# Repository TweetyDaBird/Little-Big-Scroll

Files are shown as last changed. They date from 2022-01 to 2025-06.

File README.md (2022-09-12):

# Little Big Scroll

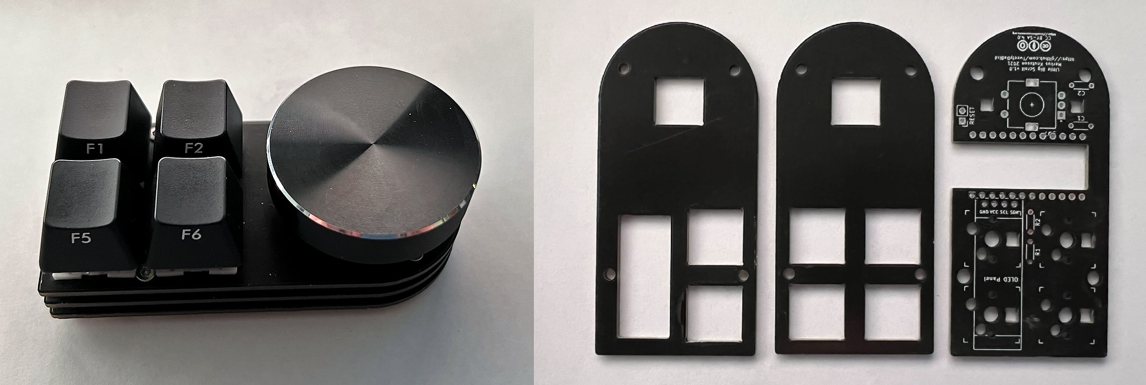
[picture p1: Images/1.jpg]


## A family of low-cost and easy to build macro pads. 
Usable for Media control, macro buttons, or just about anything else you can imagine and code in QMK.

### The 'family' includes:
- **Little Big Scroll 6** - 6 Cherry MX compatible buttons, one Ø40 mm encoder wheel with button. (Prototype being tested)
- **Little Big Scroll 4** - 2 or 4 Cherry MX compatible buttons, one Ø40 mm encoder wheel with button, optional 128x32px OLED. (Complete and available for sale/manufacturing)
- **Little Big Scroll** - A single Ø40 mm encoder wheel with button. (Design completed, pending prototype)

### Common specifications
- Use a Promicro or equivalent controller
- Programmable with QMK and VIAL
- Cherry MX style keyswitches
- Kaihl hot swap sockets
- Clickable Rotary encoder with up to 40mm wheel
- Designed with a complete sandwich case for an easy build (If purchased, comes as a complete kit)
- Optional Per Key RGB / Encoder Underglow
- (LBS 4) Optional 0.91" 128x32 OLED screen

## Buildguide

### Step-by-step
- Solder hotswap sockets in markings
- Solder capacitors C1, C2 in markings
- **LSB 4 only** - If you are mounting the OLED, solder Resistors R1, R2 & OLED Screen in place
- Solder Encoder
- Solder controller, face up, flush with underside of PCB (*)
- Assemble plate/spacers around the PCB (**)
- Insert switches/caps (remember to support the sockets!) and add encoder wheel
- Program
- Enjoy!

(*) The controller can be socketed, but that adds height, and you need longer spacers than the ones included if purchasing a kit.

(**) For LSB 4, the unused plate forms the bottom, unless a solid backplate is added as an optional extra. Breakaway tabs need to be removed and filed before use.

## Buy a kit!
I sell complete kits, making it easy to build your keyboard, and it also supports prototypes for new wacky ones. 



## Discord for build help and discussions!

<a href="https://discord.gg/G6QzcJQUnm">Discuss on Discord</a>

## License

[][cc-by-sa] - This work is licensed under a
[Creative Commons Attribution-ShareAlike 4.0 International License][cc-by-sa].

[cc-by-sa]: http://creativecommons.org/licenses/by-sa/4.0/
[cc-by-sa-shield]: https://img.shields.io/badge/License-CC%20BY--SA%204.0-lightgrey.svg

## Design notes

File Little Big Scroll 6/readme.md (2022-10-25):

# Little Big Scroll 6



A low-cost and easy to build macro pad intended for amongst other things media controls. 

- Uses a Promicro/Elite C or equivalent controller
- Programmable with QMK and VIAL
- Cherry MX style keyswitches
- Kaihl hot swap sockets
- Clickable Rotary encoder with up to 40mm wheel
- Optional Per Key RGB
- Designed with a complete sandwich case for an easy build

## BOM
| Name of part | Qty. | Remarks | Aliexpress |
| --- | ---- | --- | --- |
| PCB | 1 | 1,6 mm thick | X |
| Front Plate  | 1 |1,6 mm thick| X |
| Rear Plate | 1 | 1,6 mm thick| X |
| Kailh hotswap socket | 6 | | [link](https://www.aliexpress.com/item/-/4001051840976.html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) |
| Capacitors 100 nF | 2 | Needed for Rotary Encoder. | [link](https://www.aliexpress.com/item/-/32971478818.html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) |
| M2 * 7/8 mm standoff | 4 | Round, max 3.7 mm in diameter | [link](https://www.aliexpress.com/item/-/32863484622.html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) |
| M2 * 4 mm screw | 8 | 4-8 mm length fits, low profile hex head recommended | [link](https://www.aliexpress.com/item/-/32966917947.html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) |
| Silicon pads | 4 |  | [link](https://www.aliexpress.com/item/-/32912066603.html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) |
| Pro Micro | 1 | Can be built with various ProMicro clones as well as Elite C | [link](https://www.aliexpress.com/item/-/32849563958.html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) |
| Rotary Encoder | 1 || [link](https://www.aliexpress.com/item/10000056483250.html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,searchweb201602_,searchweb201603_) |
| Rotary Encoder Knob | 1 | Clearance for max 40 mm diameter, pick halfshaft or spline according to encoder choice.  | [link](https://www.aliexpress.com/item/10000056483250.html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,searchweb201602_,searchweb201603_) |
| RGB LED's | 8 | **- Optional -** SK6812 mini-E | [link](https://www.aliexpress.com/item/4000475685852.html) |

## Buildguide

### Step-by-step
- Solder hotswap sockets in markings
- Solder capacitors C1, C2 in markings
- Solder Encoder
- Solder controller, face up, flush with underside of PCB
- Assemble plate/spacers
- Insert switches and add encoder wheel
- Program
- Enjoy!

## License
[][cc-by-sa]  -  This work is licensed under a
[Creative Commons Attribution-ShareAlike 4.0 International License][cc-by-sa].

[cc-by-sa]: http://creativecommons.org/licenses/by-sa/4.0/
[cc-by-sa-image]: https://licensebuttons.net/l/by-sa/4.0/88x31.png
[cc-by-sa-shield]: https://img.shields.io/badge/License-CC%20BY--SA%204.0-lightgrey.svg

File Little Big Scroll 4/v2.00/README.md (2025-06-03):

# Little Big Scroll 4 v2



A low-cost and easy to build macro pad intended for among other things media controls. 

- Uses an RP2040 Zero or equivalent controller
- Programmable with QMK and VIAL
- Cherry MX style keyswitches
- Kaihl hot swap sockets
- Clickable Rotary encoder with up to 40mm wheel
- Optional Per Key RGB
- Designed with a complete sandwich case for an easy build

## BOM
| Name of part | Qty. | Remarks | Aliexpress |
| --- | ---- | --- | --- |
| PCB | 1 | 1,6 mm thick | X |
| Plate Front  | 1 |1,6 mm thick| X |
| Plate Rear | 1 | 1,6 mm thick| X |
| Kailh hotswap socket | 4 | Qty. depends on layout. | [link](https://www.aliexpress.com/item/-/4001051840976.html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) |
| Capacitors 100 nF | 2 | Needed for Rotary Encoder. | [link](https://www.aliexpress.com/item/-/32971478818.html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) |
| M2 * 7/8 mm standoff | 4 | Round, max 3.7 mm in diameter | [link](https://www.aliexpress.com/item/-/32863484622.html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) |
| M2 * 4 mm screw | 8 | 4-8 mm length fits, low profile hex head recommended | [link](https://www.aliexpress.com/item/-/32966917947.html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) |
| Silicon pads | 4 |  | [link](https://www.aliexpress.com/item/-/32912066603.html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) |
| RP2040 Zero | 1 | | [link](https://www.aliexpress.com/item/1005003504006451.html) |
| Rotary Encoder | 1 || [link](https://www.aliexpress.com/item/10000056483250.html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,searchweb201602_,searchweb201603_) |
| Rotary Encoder Knob | 1 | Clearance for max 40 mm diameter, pick halfshaft or spline according to encoder choice.  | [link](https://www.aliexpress.com/item/10000056483250.html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,searchweb201602_,searchweb201603_) |
| RGB LED's | 6 | **- Optional -** SK6812 mini-E | [link](https://www.aliexpress.com/item/4000475685852.html) |

## Buildguide

### Step-by-step
- Solder hotswap sockets in markings on rear of PCB
- Solder capacitors C1, C2 in markings on rear of PCB
- Solder Encoder (Place from front, solder on the back)
- Solder controller (**Place behind the PCB**, buttons facing up).
- Assemble plate & spacers.
- Insert switches and add encoder wheel
- Program
- Enjoy!

## License
[][cc-by-sa]  -  This work is licensed under a
[Creative Commons Attribution-ShareAlike 4.0 International License][cc-by-sa].

[cc-by-sa]: http://creativecommons.org/licenses/by-sa/4.0/
[cc-by-sa-image]: https://licensebuttons.net/l/by-sa/4.0/88x31.png
[cc-by-sa-shield]: https://img.shields.io/badge/License-CC%20BY--SA%204.0-lightgrey.svg

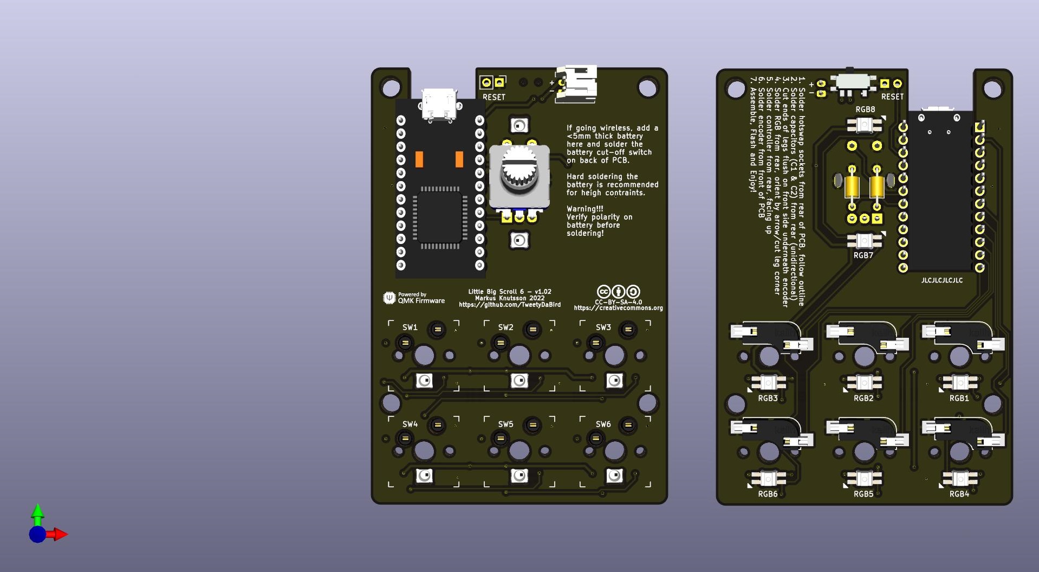
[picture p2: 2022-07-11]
Images/Ny mapp/Little Big Scroll 6 front.jpg

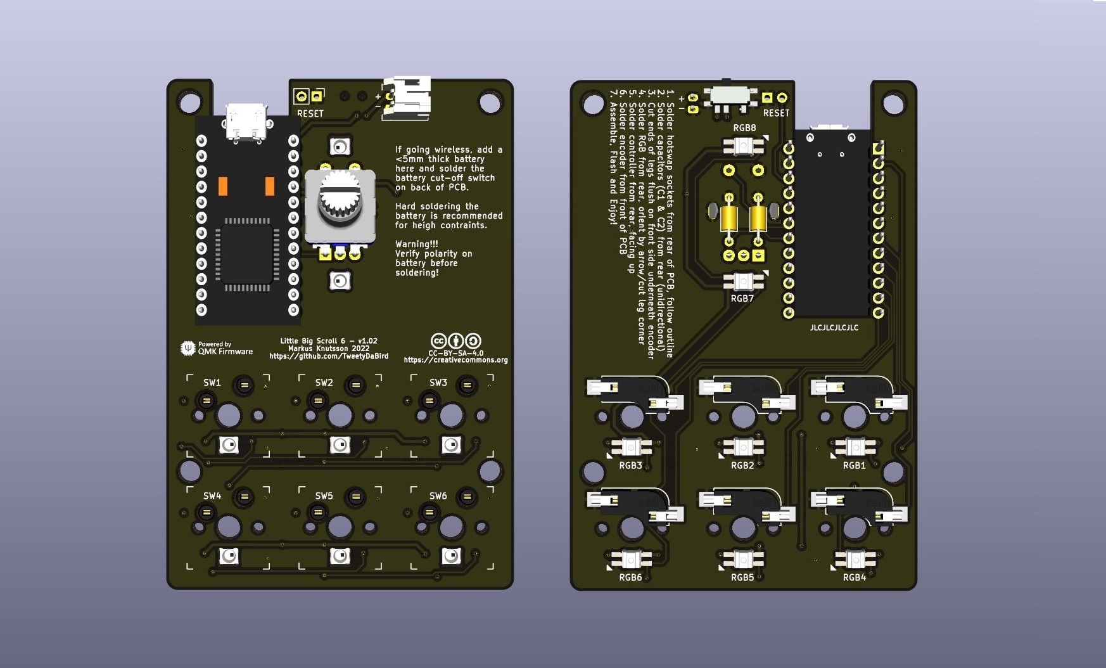
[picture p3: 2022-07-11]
Images/Ny mapp/Little Big Scroll 6 composite.jpg

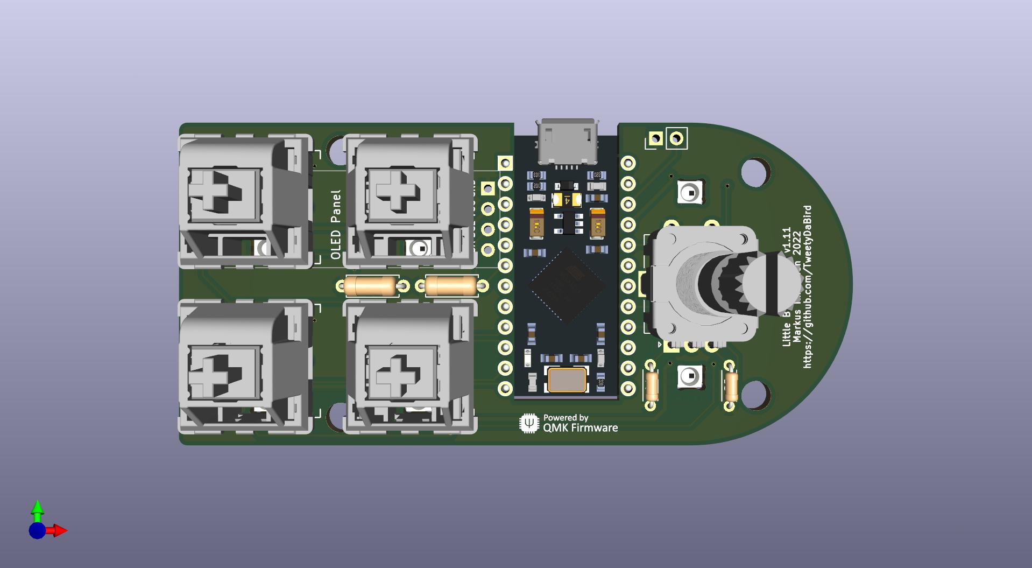
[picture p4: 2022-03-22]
Images/Little_Big_Scroll_4_front.jpg

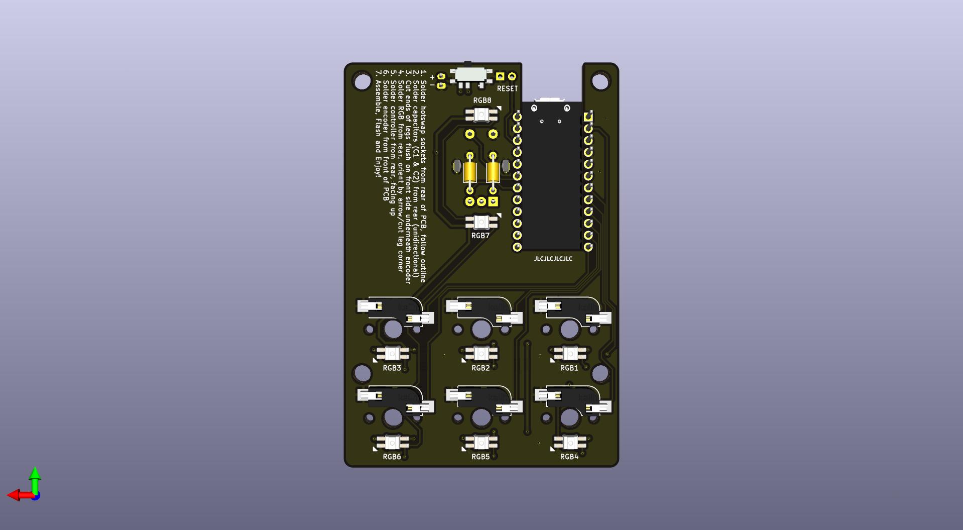
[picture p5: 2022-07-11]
Images/Ny mapp/Little Big Scroll 6 rear.jpg

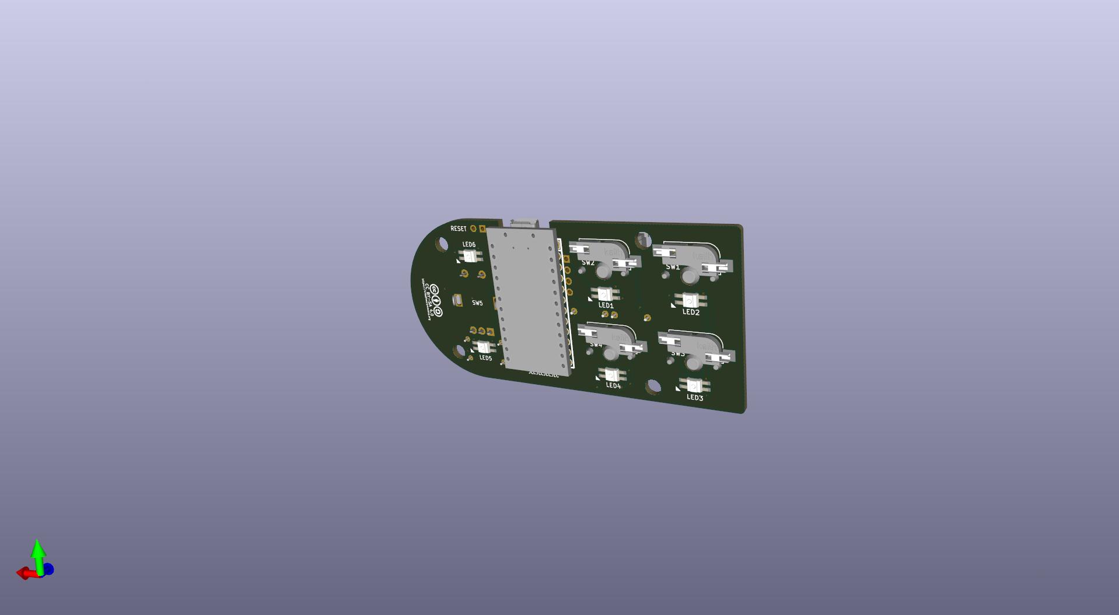
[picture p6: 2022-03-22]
Images/Little_Big_Scroll_4_back.jpg

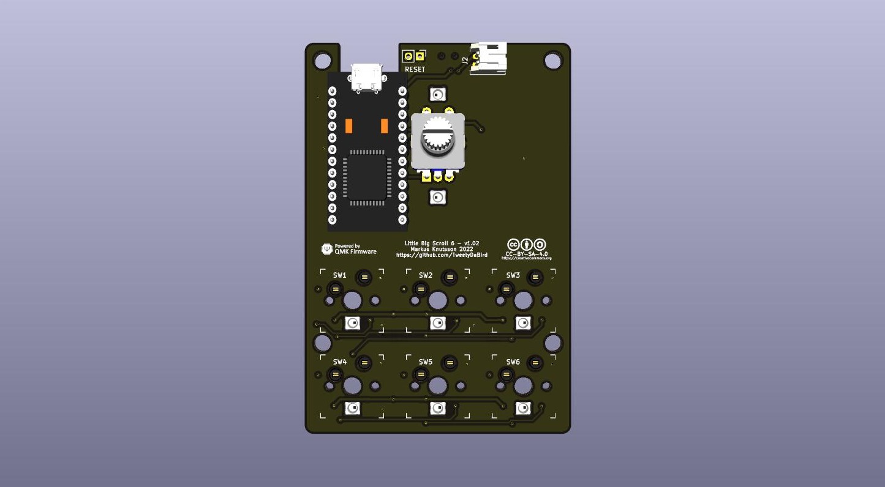
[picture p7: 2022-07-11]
Images/Little Big Scroll 6 2.jpg

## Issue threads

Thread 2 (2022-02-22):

Vial-QMK Firmware source code

kroegerama, 2022-02-22:
This is an interesting project, but where can I find the source code of your hex file?

I can't find the Little-Big-Scroll in [`vial-qmk`](https://github.com/vial-kb/vial-qmk/tree/vial/keyboards/) or in your fork of [`qmk-firmware`](https://github.com/TweetyDaBird/qmk_firmware/tree/tweetydabird/keyboards).

TweetyDaBird, 2022-02-22:
That’s because I’m lazy and haven’t finished tweaking them yet. I got distracted playing with the prototype for the LittleBigScroll 6 instead. I’ll get around to finish them in a couple of days probably.

kroegerama, 2022-02-22:
Oh, I can totally relate to that 😄  Thanks for letting me know!

TweetyDaBird, 2022-03-22:
Well, life keeps interfering unfortunately. I will get to to it I promise.

Side note, what kind of troubleshooting is it you need the firmware for? All the info you would ever need is in the pdf file with the schematic.

lesshonor, 2022-04-27:
Late, but the disconnect ended up being that the seller of the PCBs used the v1.1 release to get the files made, and that has _wildly_ different pin definitions from "v1.11".
(Would you consider calling this "rev 2" so that distinction is clearer? These are breaking changes. https://semver.org/)

TweetyDaBird, 2022-04-27:
Well, considering nothing reached beyond pre-releases before v1.11 I think it should be fine as is, although I can understand the confusion.

Brittle73, 2022-06-15:
> That’s because I’m lazy and haven’t finished tweaking them yet. I got distracted playing with the prototype for the LittleBigScroll 6 instead. I’ll get around to finish them in a couple of days probably.

Do you have an update?

TweetyDaBird, 2022-10-01:
LSB 4 & LSB 6 is now in main QMK repo, so should be less confusing.

* Note that using QMK online Configurator still isn't a great idea, since the main feature, ie the encoder won't work in that case.

VIAL firmware is available in my fork, but remains WIP for now.

TweetyDaBird, 2022-10-25:
VIAL is merged into main Git, source code is available, and pre configured .HEX files are available in this Git

Closed 2022-10-25.

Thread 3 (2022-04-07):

QMK keyboard firmware

kilokeith, 2022-04-07:
Hi, I've putting together a Little Big Scroll 4, but I'm stuck at the programming step. What keyboard should I tell QMK that I'm flashing?
I do se the .hex file in this project, and I can flash that... but then what? Where should I start with putting together a layout?

Thanks! This is a nice project.

TweetyDaBird, 2022-04-08:
Thanks for the praise, but unfortunately you will get a slightly testy reply back, as this is a clear issue of not reading, not the instructions being unclear in any way. I will however update them to be overly obvious from now on, as this seems to be a common issue.

Why do people insist on trying to 'tell QMK what keyboard they are flashing'? The label on that drop box clearly states "Keyboard from qmk.fm" meaning it will download the firmware for the keyboard you select from that database. And obviously if the keyboard is not in that database, you cannot download it from there.

The dropdown has nothing to do with what keyboard you are flashing, but with what file you want to download. If you were in fact using QMK and building your own layout as you allude to, selecting a firmware from here would flash the default firmware with the default layout as downloaded, not your own layout.

The supplied .HEX file is for VIAL-QMK. Download the software [here](https://get.vial.today) and then you have all the options to dynamically assign keys, just like VIA does, only open source. The firmware supports RGB as backlight, not a matrix, since 2*3 is a bit limiting anyways.

If you very much prefer to use QMK without VIAL, you will either have to build the firmware on your own from the files supplied in the QMK git under my username, or wait until its in the QMK main git.

Brittle73, 2022-06-15:
Seconding this...

Got ghosted by you on Tindie after weeks of discussion over this. Let's not be "testy" with people who are nicely and justifiably requesting support on an open source platform like OP here. Their request was overwhelmingly positive and reasonable. QMK _is_ open source and the provided firmware for VIAL does not perform all of the functionality advertised with the product. They just asked for assistance with the product you sold them.

TweetyDaBird, 2022-06-15:
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

Sorry you feel that way. I have been working on the firmware the last week or so every free night, and it should be ready to be published in a nights work or two, giving you all a base to work from.

The 'ghosting' is probably more part of me leaving tindie altogether since they refuse to do anything to support EU tax rules, or any form of shipping calculations, meaning I was making losses on all shipping. Right now the shop there is sort of deactivated and about to time out.

TweetyDaBird, 2022-10-01:
LSB 4 & LSB 6 is now in main QMK repo, so should be less confusing.

* Note that using QMK Configurator still isn't a great idea, since the main feature, ie the encoder won't work in that case.

Closed 2022-10-01.

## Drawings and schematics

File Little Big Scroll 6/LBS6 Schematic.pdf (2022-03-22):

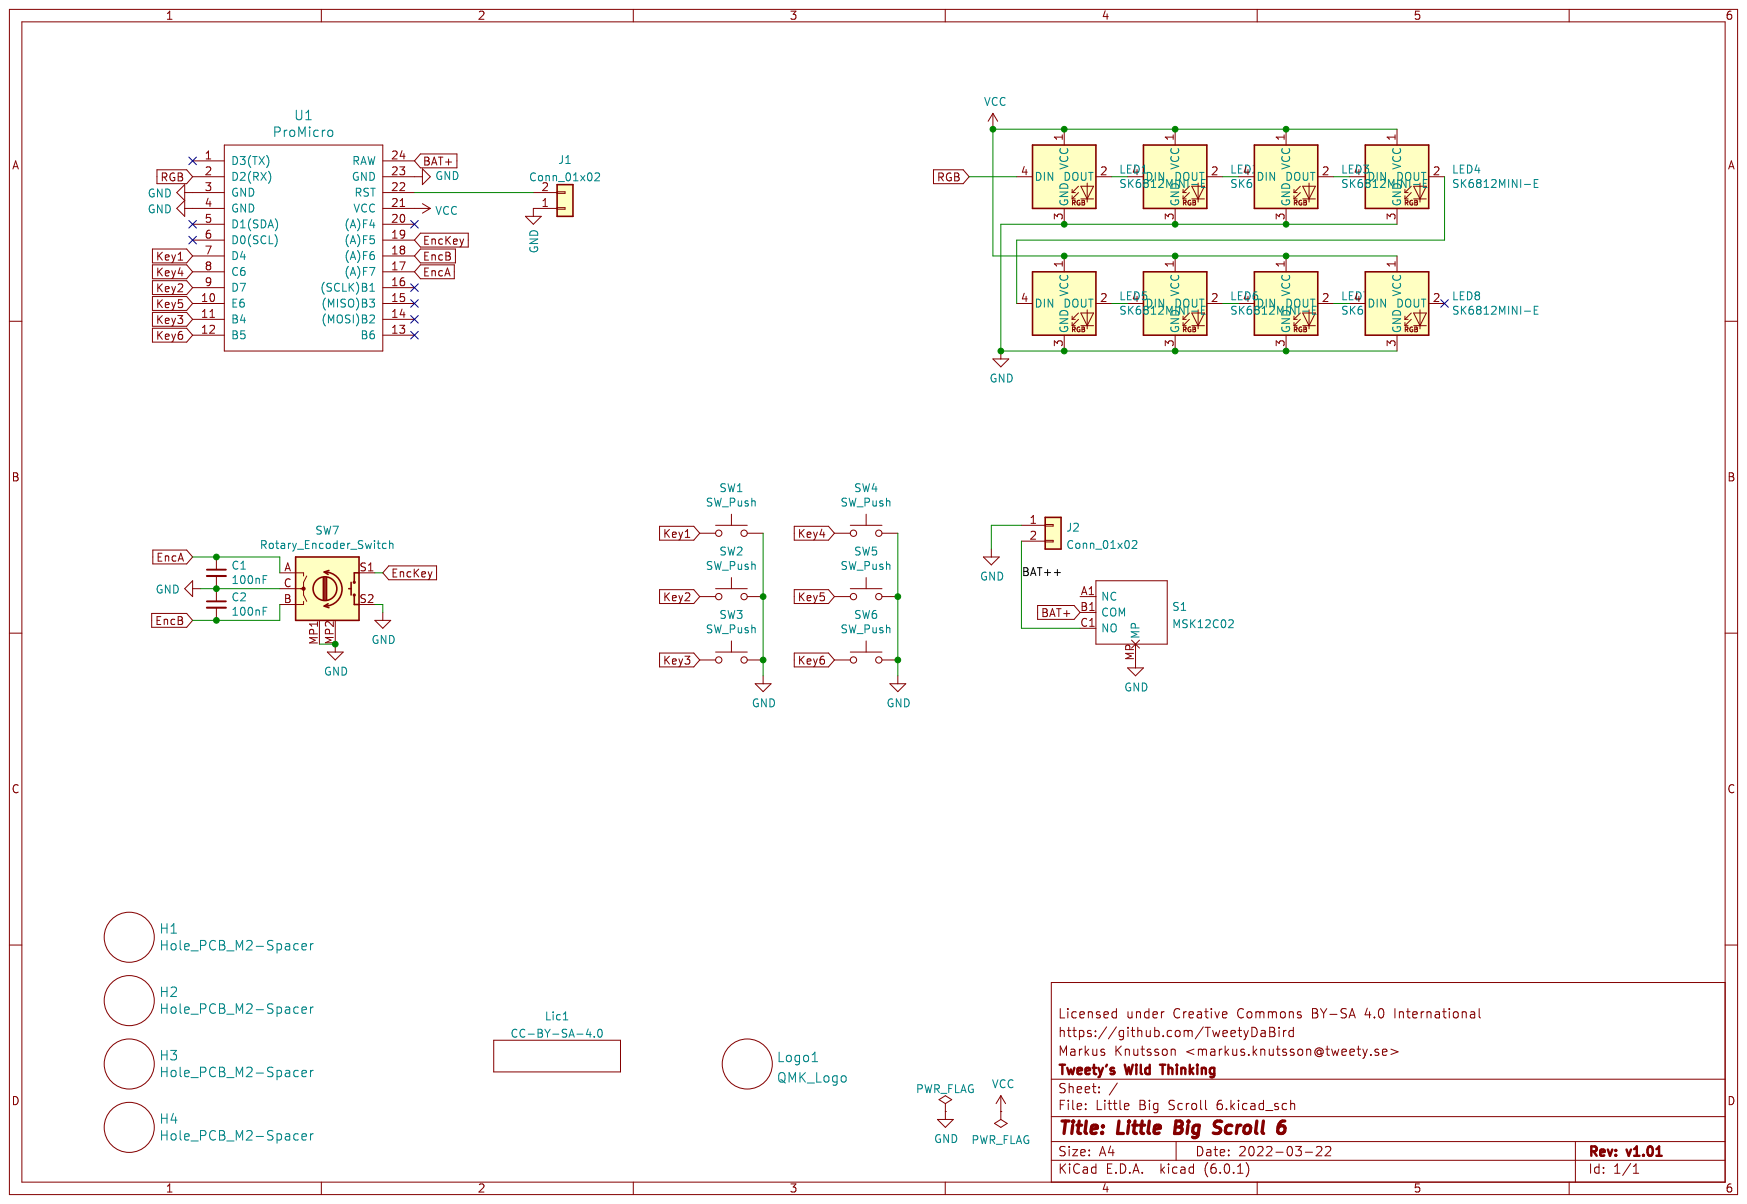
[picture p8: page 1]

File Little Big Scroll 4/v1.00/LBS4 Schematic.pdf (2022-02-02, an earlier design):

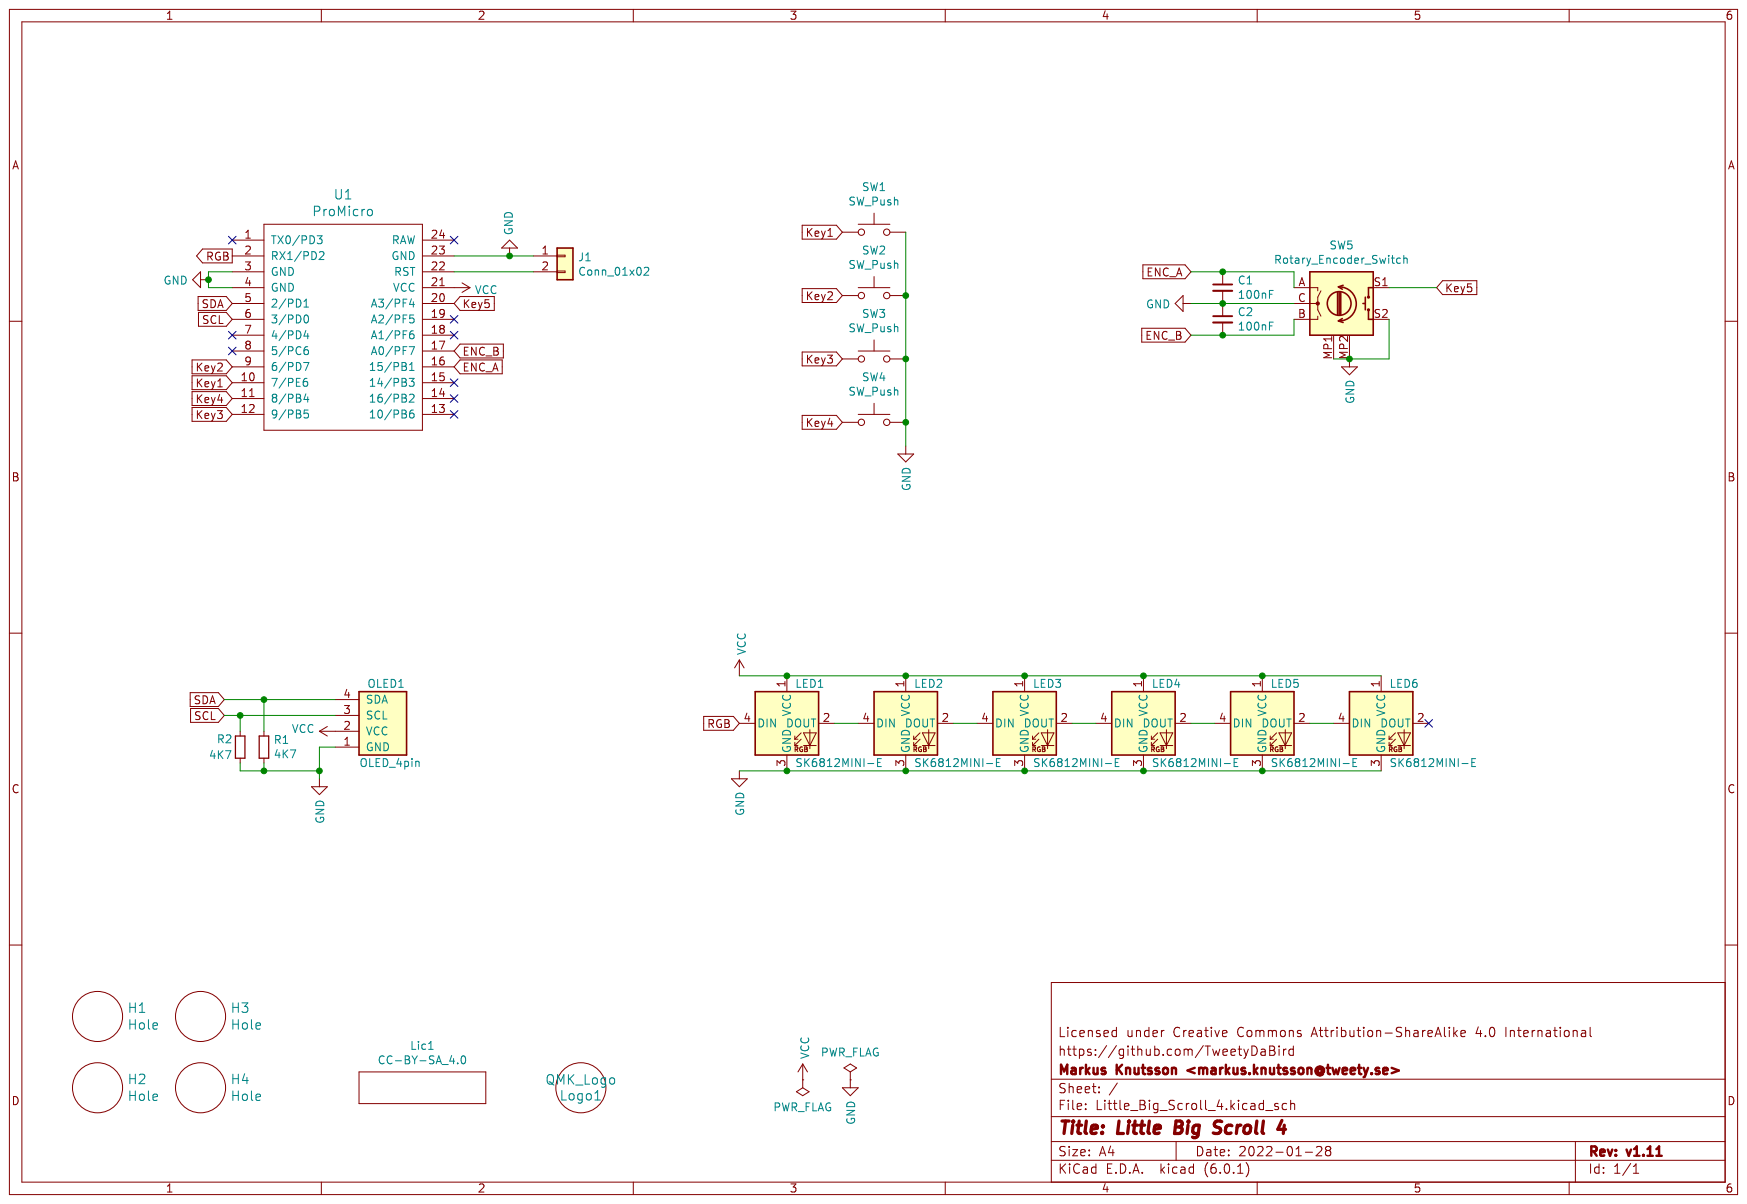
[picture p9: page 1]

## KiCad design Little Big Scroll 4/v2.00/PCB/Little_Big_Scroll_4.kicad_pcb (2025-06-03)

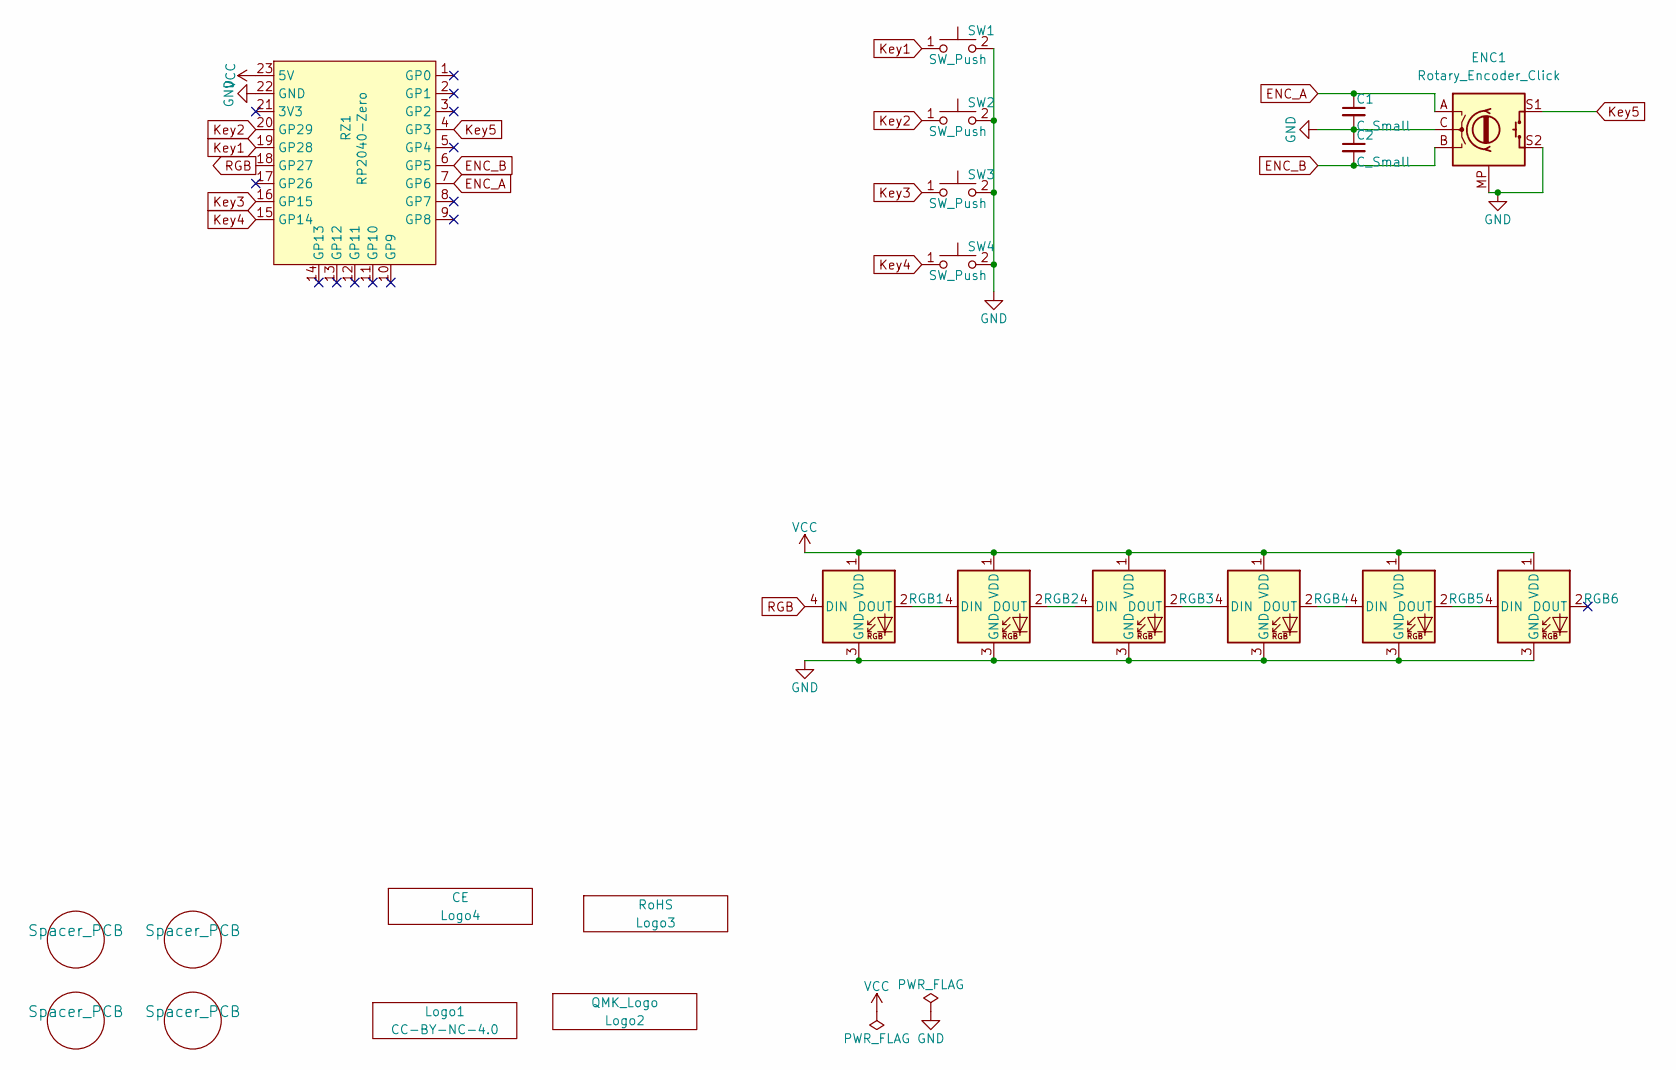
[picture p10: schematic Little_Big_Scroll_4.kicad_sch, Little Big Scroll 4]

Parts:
C1, C2: C_Small
ENC1: Rotary_Encoder_Click; Encoder_Alps_EC11E_Small
H1, H2, H3, H4: Spacer_PCB; Spacer PCB hole
Logo1: CC-BY-NC-4.0; CC_BY_SA_40_line
Logo2: QMK_Logo; Powered_by_QMK
Logo3: RoHS; RoHs
Logo4: CE
RGB1, RGB2, RGB3, RGB4, RGB5, RGB6: SK6812MINI-E; RGB_SK6812MINI-E
RZ1: RP2040-Zero
SW1, SW2, SW3, SW4: SW_Push; SW_MX_HotSwap

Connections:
ENC_A: C1.1, ENC1.A, RZ1.7 (GP6)
ENC_B: C2.2, ENC1.B, RZ1.6 (GP5)
GND: C1.2, C2.1, ENC1.C, ENC1.MP (GND), ENC1.S2, RGB1.3 (GND), RGB2.3 (GND), RGB3.3 (GND), RGB4.3 (GND), RGB5.3 (GND), RGB6.3 (GND), RZ1.22 (GND), SW1.2, SW2.2, SW3.2, SW4.2
Key1: RZ1.19 (GP28), SW1.1
Key2: RZ1.20 (GP29), SW2.1
Key3: RZ1.16 (GP15), SW3.1
Key4: RZ1.15 (GP14), SW4.1
Key5: ENC1.S1, RZ1.4 (GP3)
unnamed: RGB1.2 (DOUT), RGB2.4 (DIN)
unnamed: RGB2.2 (DOUT), RGB3.4 (DIN)
unnamed: RGB3.2 (DOUT), RGB4.4 (DIN)
unnamed: RGB4.2 (DOUT), RGB5.4 (DIN)
unnamed: RGB5.2 (DOUT), RGB6.4 (DIN)
RGB: RGB1.4 (DIN), RZ1.18 (GP27)
VCC: RGB1.1 (VDD), RGB2.1 (VDD), RGB3.1 (VDD), RGB4.1 (VDD), RGB5.1 (VDD), RGB6.1 (VDD), RZ1.23 (5V)

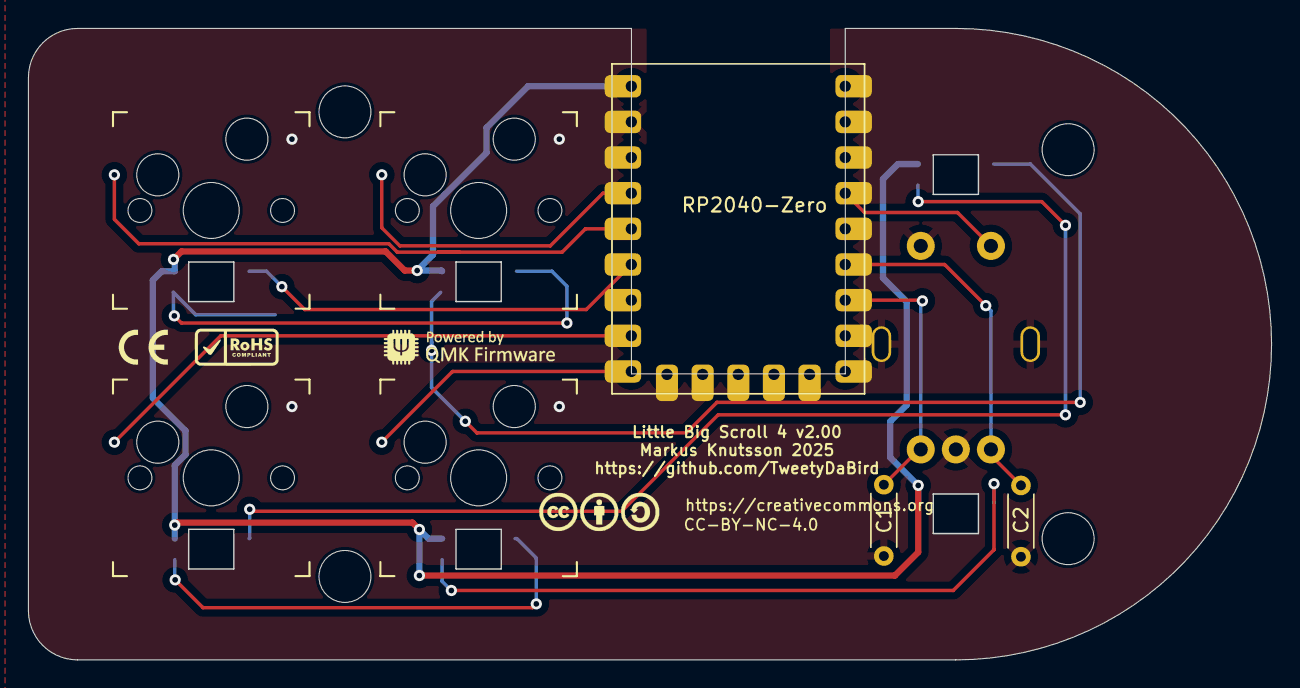
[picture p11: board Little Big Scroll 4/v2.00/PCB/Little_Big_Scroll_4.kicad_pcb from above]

Board: 2 copper layers, 88.6 x 45.0 mm, 22 parts (0 on the bottom side), 15 nets.

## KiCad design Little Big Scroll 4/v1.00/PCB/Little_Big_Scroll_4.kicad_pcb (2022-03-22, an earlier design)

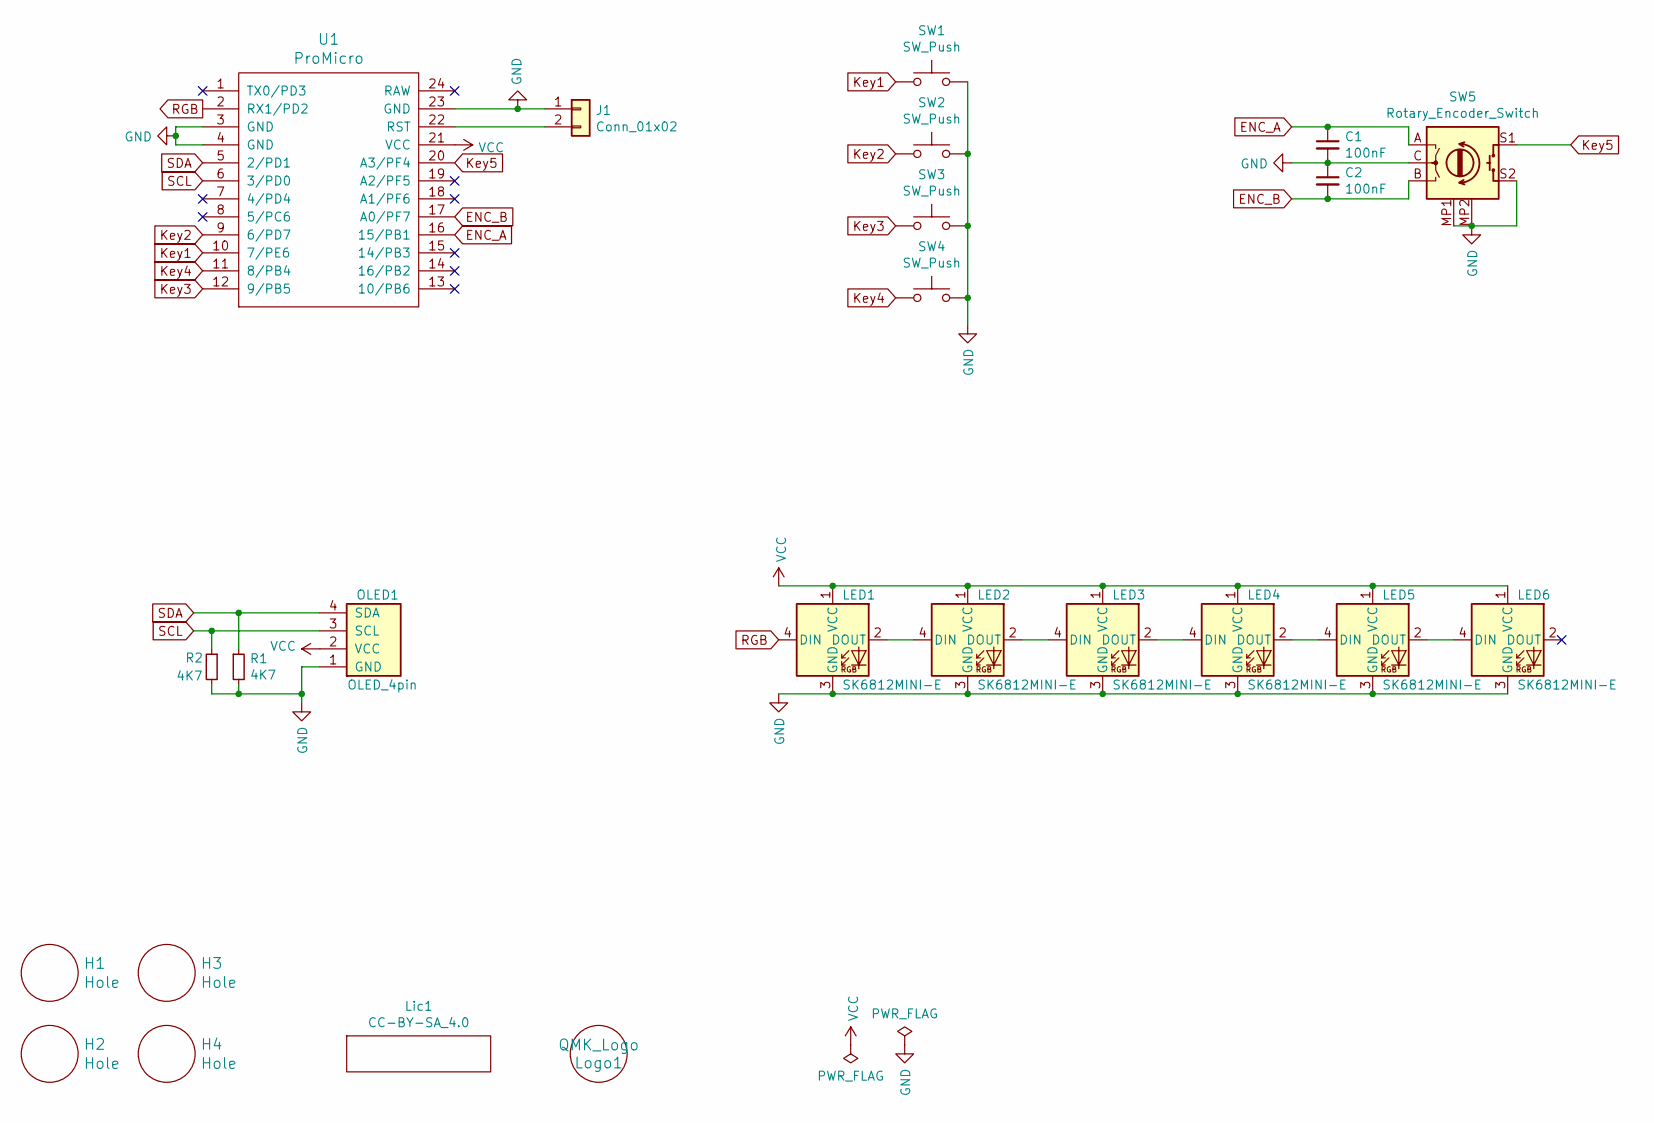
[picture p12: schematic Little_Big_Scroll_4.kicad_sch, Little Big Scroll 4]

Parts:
C1, C2: 100nF; R_Axial_DIN0204_L3.6mm_D1.6mm_P5.08mm_Horizontal
H1, H2, H3, H4: Hole; MountingHole_3.7mm
J1: Conn_01x02; PinHeader_1x02_P2.54mm_Vertical
LED1, LED2, LED3, LED4, LED5, LED6: SK6812MINI-E; MX_SK6812MINI-E
Lic1: CC-BY-SA_4.0; CC_BY_SA_40
Logo1: QMK_Logo; Powered_by_QMK
OLED1: OLED_4pin; SSD1306-0.91-OLED-4pin-128x32
R1, R2: 4K7; R_Axial_DIN0207_L6.3mm_D2.5mm_P7.62mm_Horizontal
SW1, SW2, SW3, SW4: SW_Push; Kailh_socket_MX_RGB
SW5: Rotary_Encoder_Switch; RotaryEncoder_Alps_EC11E-Switch_Vertical_H20mm
U1: ProMicro; ArduinoProMicro-BackSide

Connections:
ENC_A: C1.1, SW5.A, U1.16 (15/PB1)
ENC_B: C2.2, SW5.B, U1.17 (A0/PF7)
GND: C1.2, C2.1, J1.1, LED1.3 (GND), LED2.3 (GND), LED3.3 (GND), LED4.3 (GND), LED5.3 (GND), LED6.3 (GND), OLED1.1 (GND), R1.2, R2.2, SW1.1, SW2.1, SW3.1, SW4.1, SW5.C, SW5.MP1 (GND), SW5.MP2 (GND), SW5.S2, U1.3 (GND), U1.4 (GND), U1.23 (GND)
Key1: SW1.2, U1.10 (7/PE6)
Key2: SW2.2, U1.9 (6/PD7)
Key3: SW3.2, U1.12 (9/PB5)
Key4: SW4.2, U1.11 (8/PB4)
Key5: SW5.S1, U1.20 (A3/PF4)
unnamed: J1.2, U1.22 (RST)
unnamed: LED1.2 (DOUT), LED2.4 (DIN)
unnamed: LED2.2 (DOUT), LED3.4 (DIN)
unnamed: LED3.2 (DOUT), LED4.4 (DIN)
unnamed: LED4.2 (DOUT), LED5.4 (DIN)
unnamed: LED5.2 (DOUT), LED6.4 (DIN)
RGB: LED1.4 (DIN), U1.2 (RX1/PD2)
SCL: OLED1.3 (SCL), R2.1, U1.6 (3/PD0)
SDA: OLED1.4 (SDA), R1.1, U1.5 (2/PD1)
VCC: LED1.1 (VCC), LED2.1 (VCC), LED3.1 (VCC), LED4.1 (VCC), LED5.1 (VCC), LED6.1 (VCC), OLED1.2 (VCC), U1.21 (VCC)

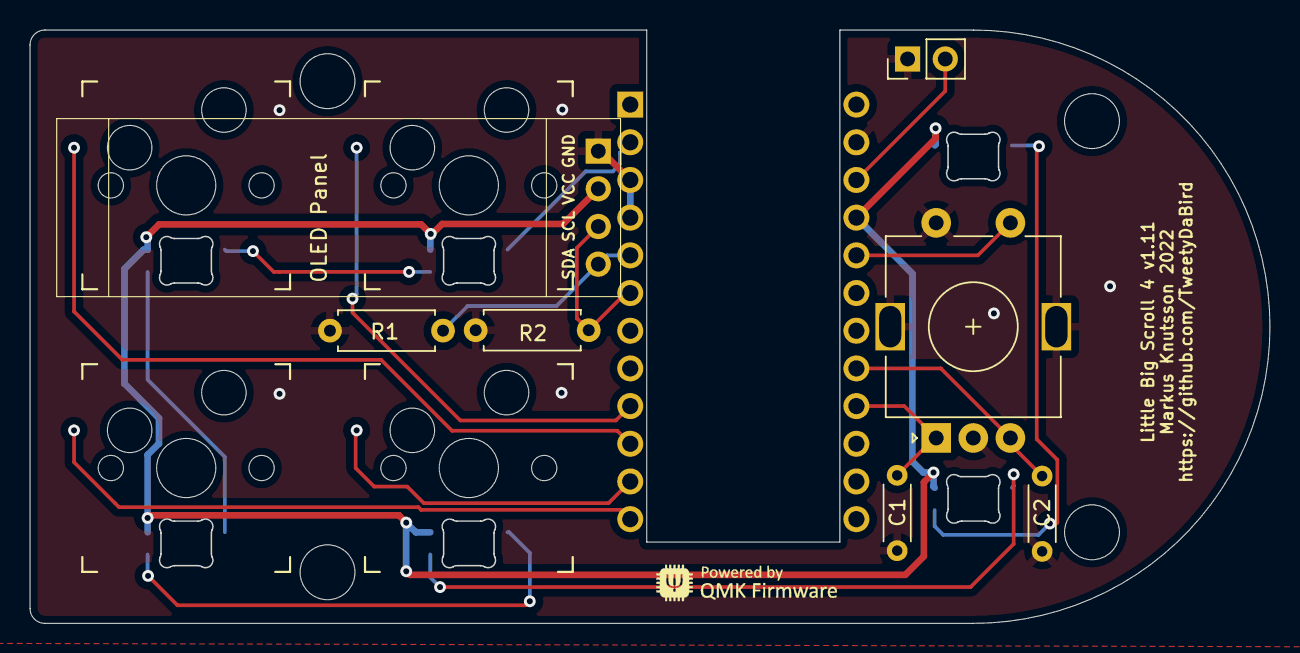
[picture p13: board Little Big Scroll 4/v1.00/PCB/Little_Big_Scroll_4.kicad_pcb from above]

Board: 2 copper layers, 83.6 x 40.0 mm, 24 parts (1 on the bottom side), 18 nets.

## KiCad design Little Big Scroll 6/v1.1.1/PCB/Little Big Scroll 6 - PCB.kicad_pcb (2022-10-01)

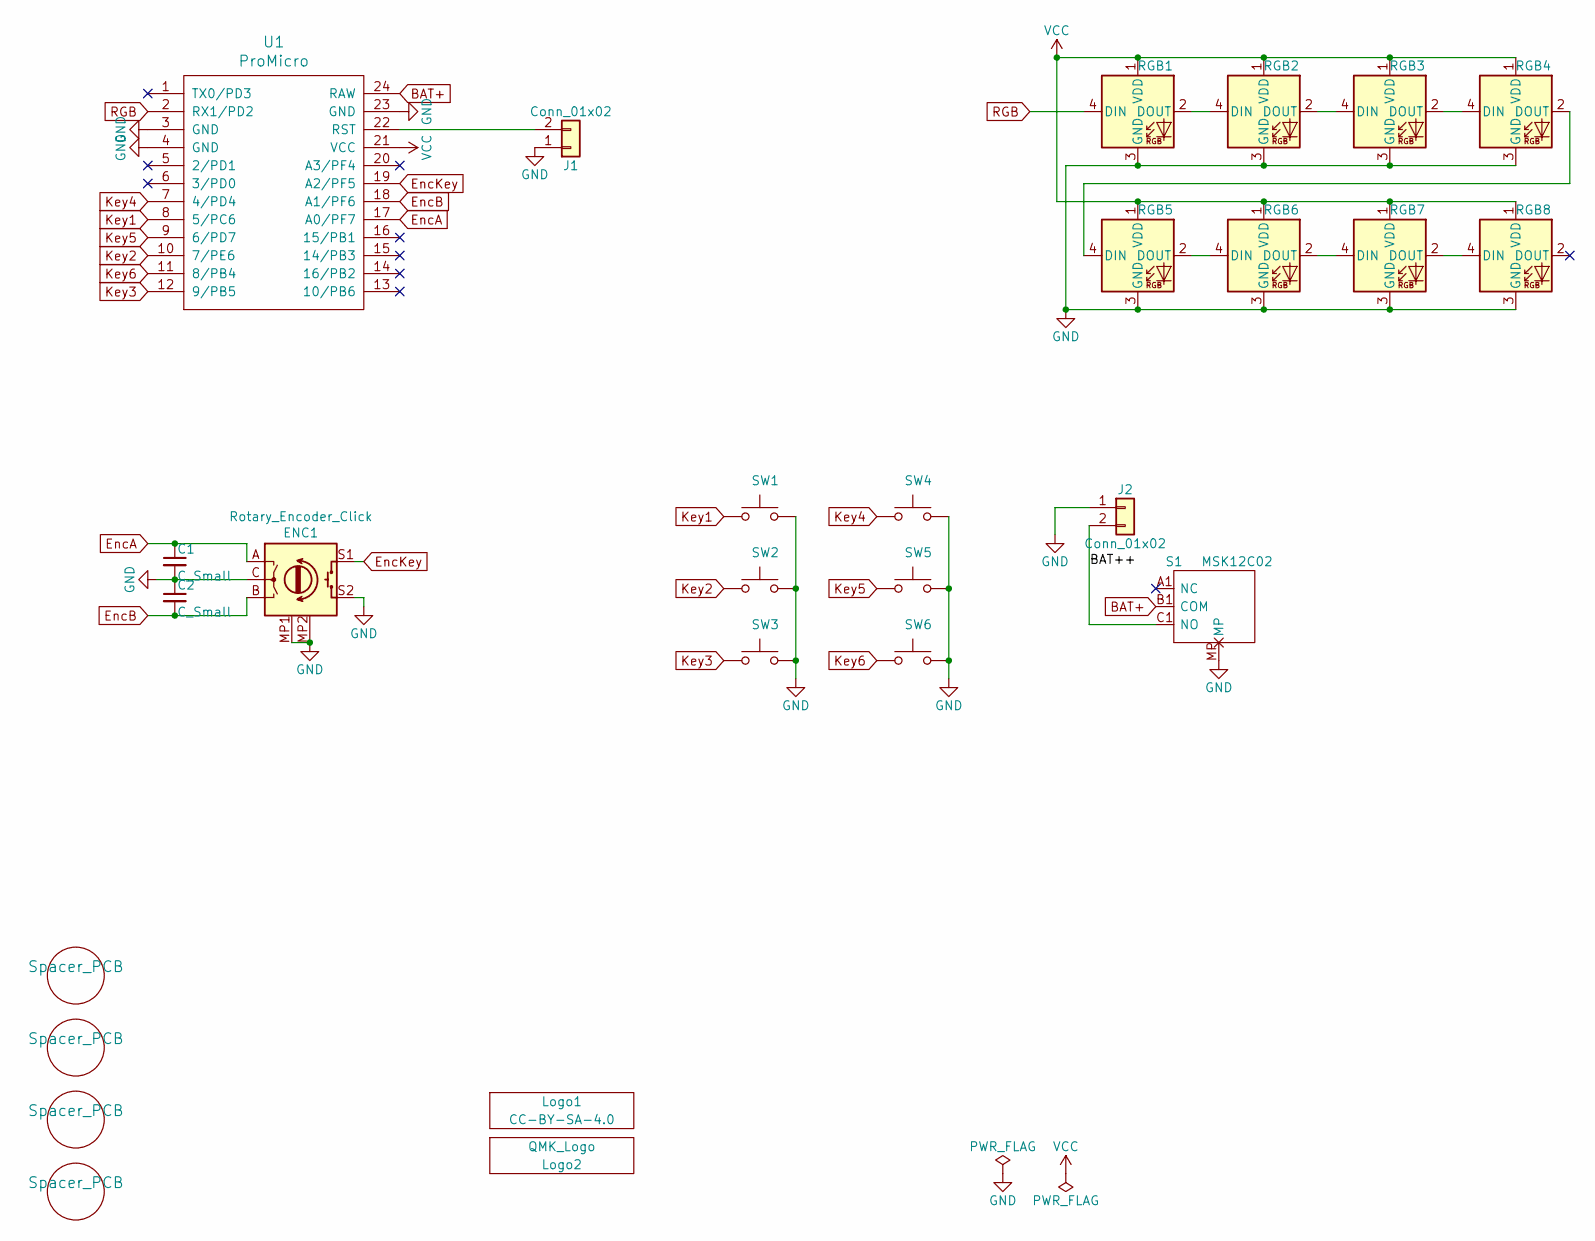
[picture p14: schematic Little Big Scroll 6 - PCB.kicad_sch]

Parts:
C1, C2: C_Small; C_Axial_L3.8mm_D2.6mm_P7.50mm_Horizontal
ENC1: Rotary_Encoder_Click; Encoder_Alps_EC11E_Small
H1, H2, H3, H4: Spacer_PCB; Spacer PCB hole
J1: Conn_01x02; PinHeader_1x02_P2.54mm_Vertical
J2: Conn_01x02; JST_PH_S2B-PH-K_1x02_P2.00mm_Horizontal
Logo1: CC-BY-SA-4.0; CC_BY_SA_40
Logo2: QMK_Logo; Powered_by_QMK
RGB1, RGB2, RGB3, RGB4, RGB5, RGB6, RGB7, RGB8: SK6812MINI-E; RGB_SK6812MINI-E
S1: MSK12C02; Manufacturer_Part_Number MSK12C02
SW1, SW2, SW3, SW4, SW5, SW6: SW_MX_HS; SW_MX_HotSwap
U1: ProMicro

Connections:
/BAT++: J2.2, S1.C1 (NO)
BAT+: S1.B1 (COM), U1.24 (RAW)
EncA: C1.1, ENC1.A, U1.17 (A0/PF7)
EncB: C2.2, ENC1.B, U1.18 (A1/PF6)
EncKey: ENC1.S1, U1.19 (A2/PF5)
GND: C1.2, C2.1, ENC1.C, ENC1.MP1 (GND), ENC1.MP2 (GND), ENC1.S2, J1.1, J2.1, RGB1.3 (GND), RGB2.3 (GND), RGB3.3 (GND), RGB4.3 (GND), RGB5.3 (GND), RGB6.3 (GND), RGB7.3 (GND), RGB8.3 (GND), S1.MP, SW1.2, SW2.2, SW3.2, SW4.2, SW5.2, SW6.2, U1.3 (GND), U1.4 (GND), U1.23 (GND)
Key1: SW1.1, U1.8 (5/PC6)
Key2: SW2.1, U1.10 (7/PE6)
Key3: SW3.1, U1.12 (9/PB5)
Key4: SW4.1, U1.7 (4/PD4)
Key5: SW5.1, U1.9 (6/PD7)
Key6: SW6.1, U1.11 (8/PB4)
unnamed: J1.2, U1.22 (RST)
unnamed: RGB1.2 (DOUT), RGB2.4 (DIN)
unnamed: RGB2.2 (DOUT), RGB3.4 (DIN)
unnamed: RGB3.2 (DOUT), RGB4.4 (DIN)
unnamed: RGB4.2 (DOUT), RGB5.4 (DIN)
unnamed: RGB5.2 (DOUT), RGB6.4 (DIN)
unnamed: RGB6.2 (DOUT), RGB7.4 (DIN)
unnamed: RGB7.2 (DOUT), RGB8.4 (DIN)
RGB: RGB1.4 (DIN), U1.2 (RX1/PD2)
VCC: RGB1.1 (VDD), RGB2.1 (VDD), RGB3.1 (VDD), RGB4.1 (VDD), RGB5.1 (VDD), RGB6.1 (VDD), RGB7.1 (VDD), RGB8.1 (VDD), U1.21 (VCC)

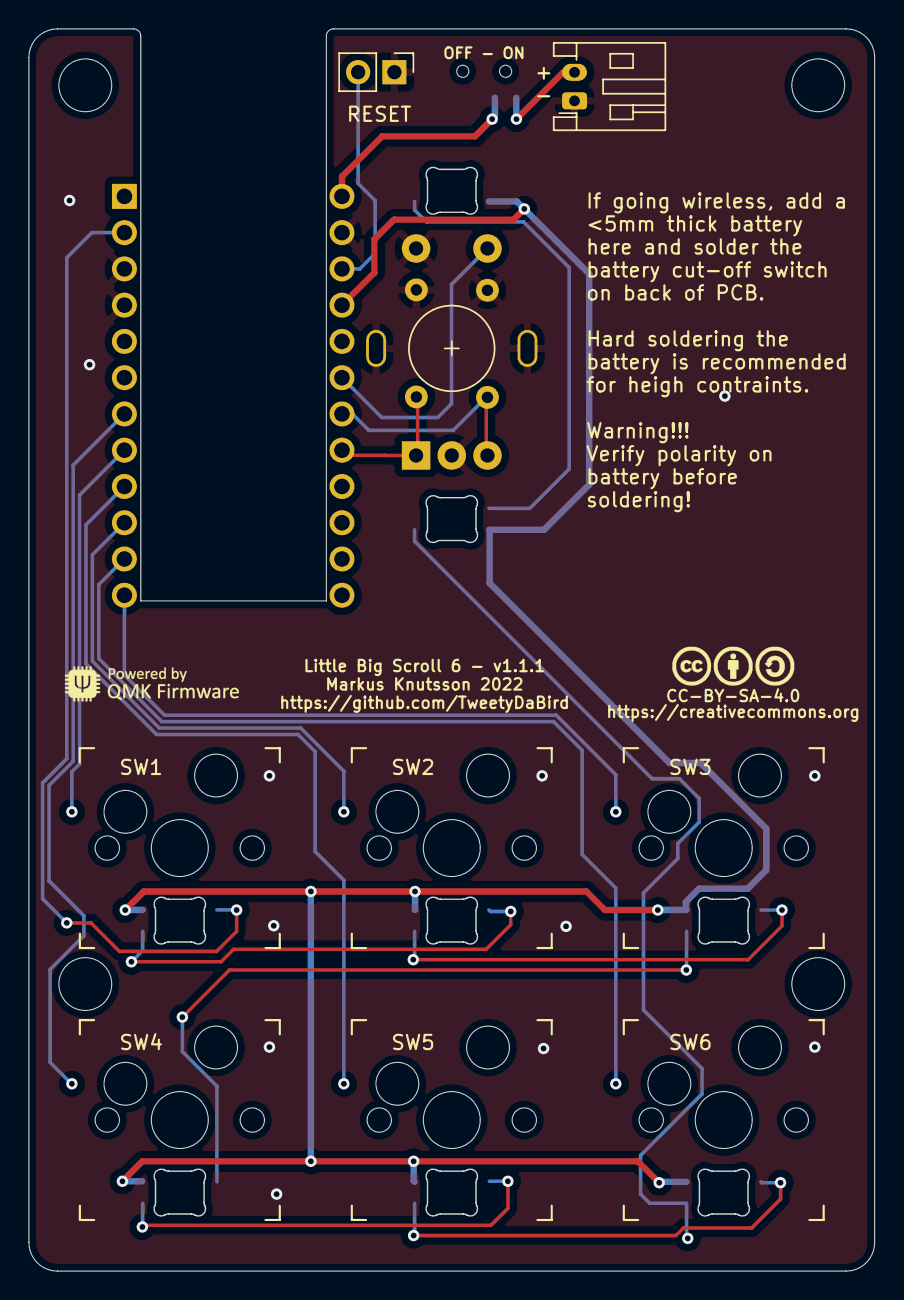
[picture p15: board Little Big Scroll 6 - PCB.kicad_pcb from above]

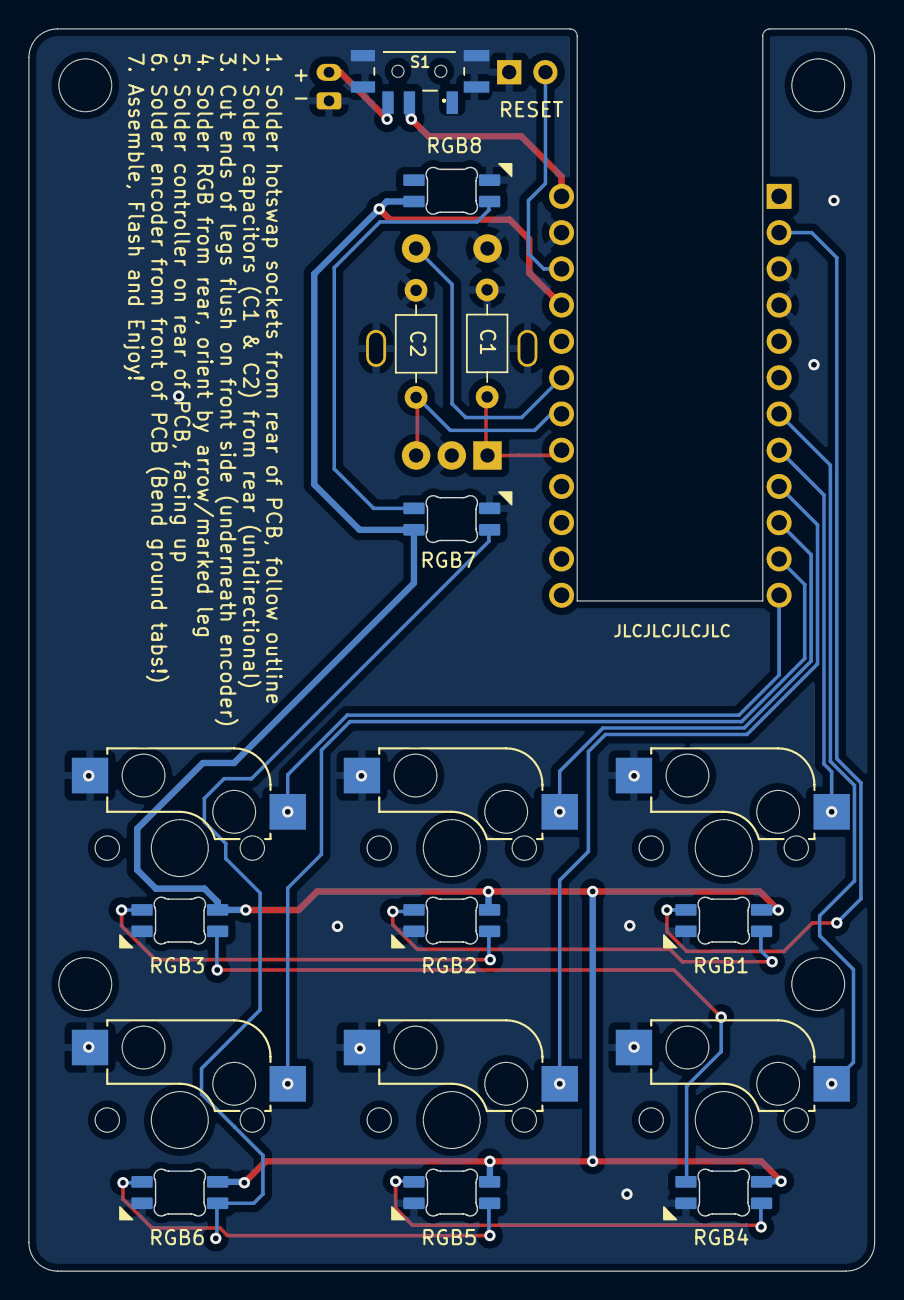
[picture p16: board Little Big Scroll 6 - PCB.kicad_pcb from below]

Board: 2 copper layers, 59.2 x 87.0 mm, 27 parts (3 on the bottom side), 22 nets.

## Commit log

2021-12-02 Renamed folders
    [Little_Big_Scroll_4KEY.kicad_pcb, Little_Big_Scroll_4KEY.sch, Little_Big_Scroll_OLED.kicad_pcb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]
2021-12-13 Added licensing on PCB
    [Little_Big_Scroll.kicad_pcb, Little_Big_Scroll_OLED.kicad_pcb]
2022-01-10 Tweaked for v1.1
    [Little_Big_Scroll.kicad_pcb, Little_Big_Scroll.sch, Little_Big_Scroll_4KEY.kicad_pcb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]
2022-01-10 moved to subfolder
    [Little_Big_Scroll.kicad_pcb, Little_Big_Scroll.sch, Little_Big_Scroll_4KEY.kicad_pcb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]
2022-01-18 Renamed to 'Little Big Scroll 4'
    [Little_Big_Scroll.kicad_pcb, Little_Big_Scroll_4.kicad_pcb, Little_Big_Scroll_4.sch]
2022-02-02 Added Little Big Scroll 6
    [LBS6_Front_Plate-B_Cu.gbl, LBS6_Front_Plate-B_Mask.gbs, LBS6_Front_Plate-B_Paste.gbp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]
2022-03-22 LBS6 v1.01
    [LBS6_Front_Plate-B_Cu.gbl, LBS6_Front_Plate-B_Mask.gbs, LBS6_Front_Plate-B_Paste.gbp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]
2022-07-11 LSB6 1.01
    [LBS6_Front_Plate-B_Cu.gbl, LBS6_Front_Plate-B_Mask.gbs, LBS6_Front_Plate-B_Paste.gbp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]
2022-09-13 LSB6 Prototype v1.1
    [LBS6_Front_Plate-B_Cu.gbl, LBS6_Front_Plate-B_Mask.gbs, LBS6_Front_Plate-B_Paste.gbp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]
2022-09-13 LSB6 v1.1
    [Little Big Scroll 6 - Front Plate-B_Cu.gbl, Little Big Scroll 6 - Front Plate-B_Mask.gbs, Little Big Scroll 6 - Front Plate-B_Paste.gbp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]
2022-09-16 LBS6 v1.1.1
    Fixed plate holes
    [Little Big Scroll 6 - Front Plate-B_Cu.gbl, Little Big Scroll 6 - Front Plate-B_Mask.gbs, Little Big Scroll 6 - Front Plate-B_Paste.gbp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]
2022-10-18 Updated LBS4 Schematic
2022-10-18 Updated LBS6 Schematic
2023-04-05 Add LBS8
    Initial Commit LBS8
    [Little Big Scroll 8 - Front.kicad_pcb, Little Big Scroll 8 - Front.kicad_sch, Little Big Scroll 8 - PCB.kicad_pcb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]
2023-04-05 Revert "Add LBS8"
    This reverts commit 78488f02631a9500abe6f1903c904799e5b784ae.
    [Little Big Scroll 8 - Front.kicad_pcb, Little Big Scroll 8 - Front.kicad_sch, Little Big Scroll 8 - PCB.kicad_pcb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]
2024-05-28 LBS 8
    initial
    [Little Big Scroll 8 - PCB.kicad_pcb]
2025-03-28 LBS 4 v2
    [Little_Big_Scroll.kicad_pcb, Little_Big_Scroll.sch, Little_Big_Scroll_4.kicad_pcb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]
2025-06-03 LSB 4 v2
    Initial design
    [Little_Big_Scroll_4.kicad_pcb, Little_Big_Scroll_4.kicad_sch]
2025-06-03 Removed WIP from main
    [LSB1 Bottom Plate-B_Cu.gbl, LSB1 Bottom Plate-B_Mask.gbs, LSB1 Bottom Plate-B_Paste.gbp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]

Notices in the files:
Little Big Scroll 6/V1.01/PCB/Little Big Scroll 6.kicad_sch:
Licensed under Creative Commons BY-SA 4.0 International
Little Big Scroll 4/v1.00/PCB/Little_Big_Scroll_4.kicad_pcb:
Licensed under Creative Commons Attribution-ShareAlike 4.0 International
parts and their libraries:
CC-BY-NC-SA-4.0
